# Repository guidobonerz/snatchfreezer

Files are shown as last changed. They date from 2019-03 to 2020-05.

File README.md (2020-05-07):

# SnatchFreezer (Beta)
SnatchFreezer is a project for Highspeed photography

Runs on Windows, Mac and Linux

This project also contains all required software and PCB layouts including:
- JavaFX - Controller Frontend
- Arduino Sketch
- Eagle PCB

Current Features:
- Connect up to six 12V driven valves or similar devices directly with 5 timing entries each.
- Connect up to two camera and/or flashes.

- Load and Save your settings
- Test all channels separately or altogether for 100ms.
- Toggle flushing all or single siphons from UI.
- Set amount of cycle loops
- Set delay time after each cycle loop.
- Describe each channel and/or the whole project
- Presets for TaT and Crown
- View log protocol
- Minimum valve delay/release time combination: 0,015 s -> 15 ms -> 15000 us / 0,004 s -> 4 ms -> 4000 us

Known Bugs:
- Data transfer sometimes hangs

Future plans:
- WLAN and/or Bluetooth Module
- Rest Api
- Android Client

# Build Java Application
mvn jfx:jar

# Download latest Frontend
[Snathfreezer Frontend](https://github.com/guidobonerz/snatchfreezer/blob/develop/download/snatchfreezer.zip)

## Shot 1
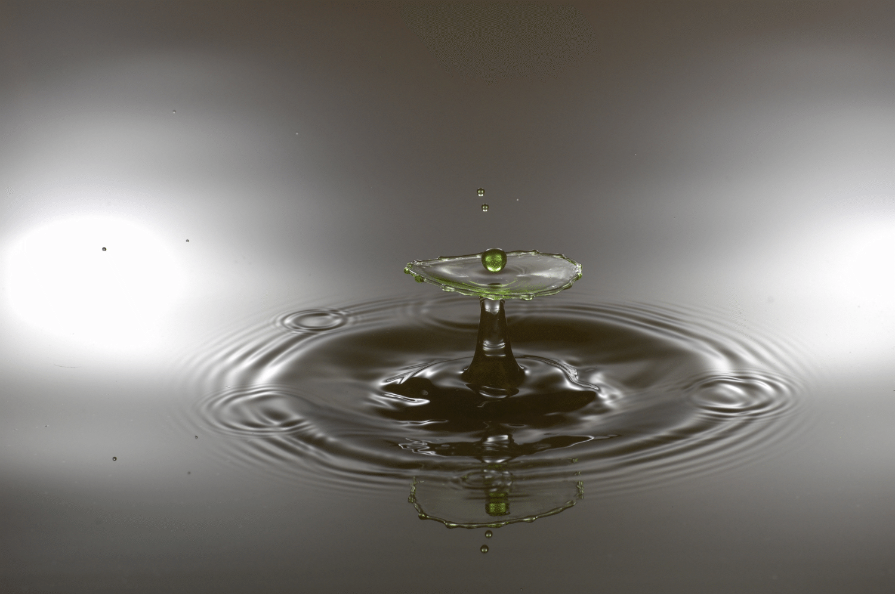
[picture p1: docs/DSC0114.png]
shot1

## Shot 2
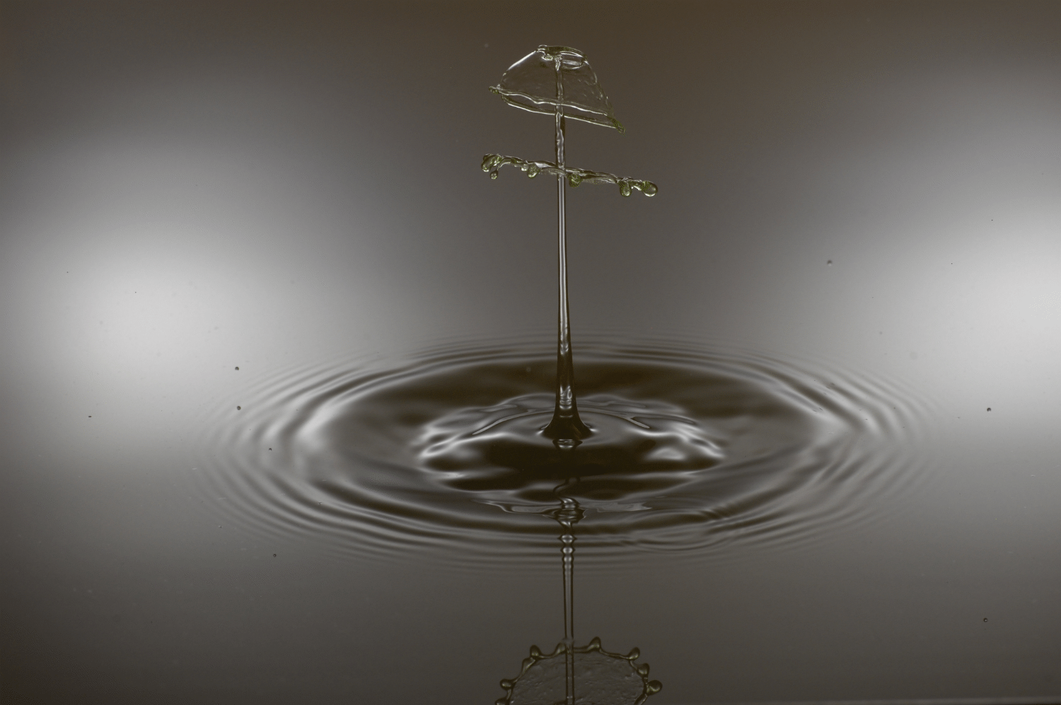
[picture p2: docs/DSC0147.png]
shot2


## Controller View
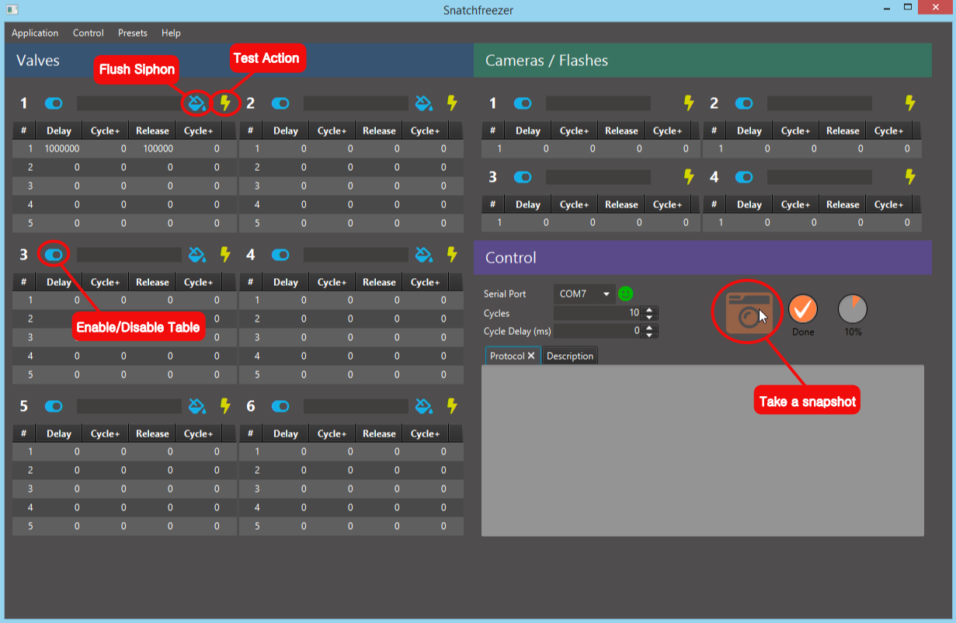
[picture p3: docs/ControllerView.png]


## PCB
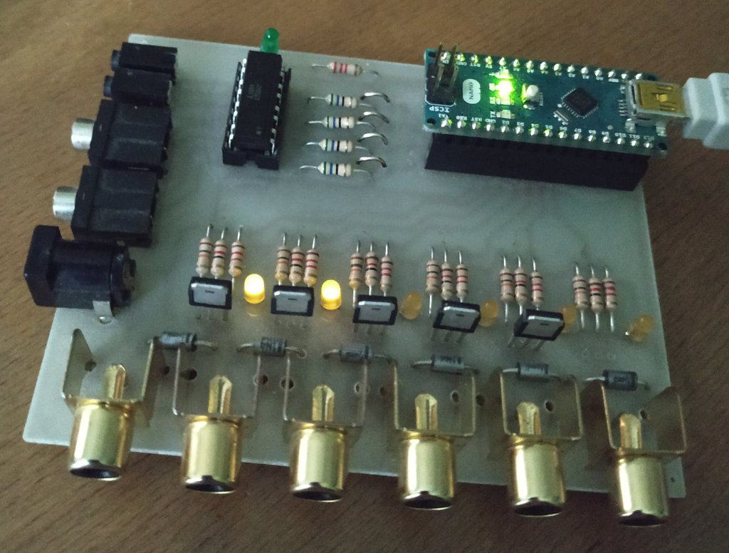
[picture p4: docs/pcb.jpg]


## Frame
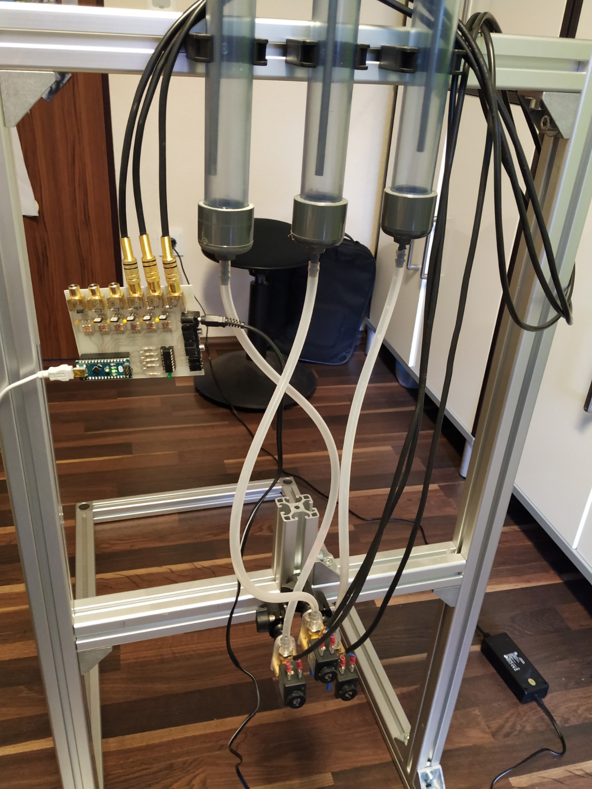
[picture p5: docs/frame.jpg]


## Siphons
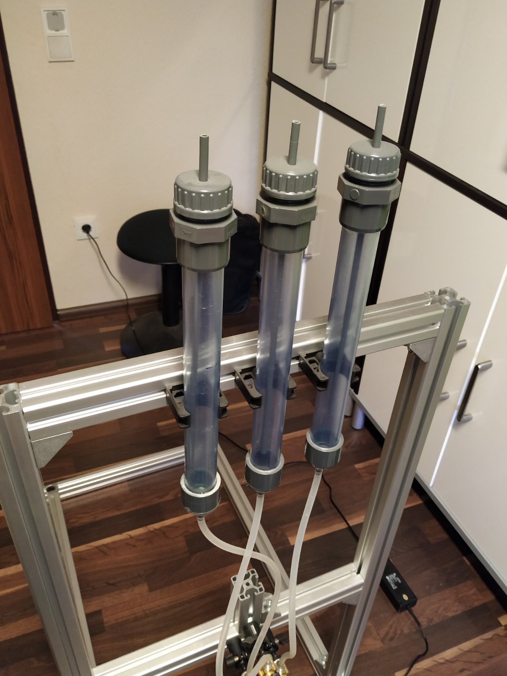
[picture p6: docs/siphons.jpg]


## Valves
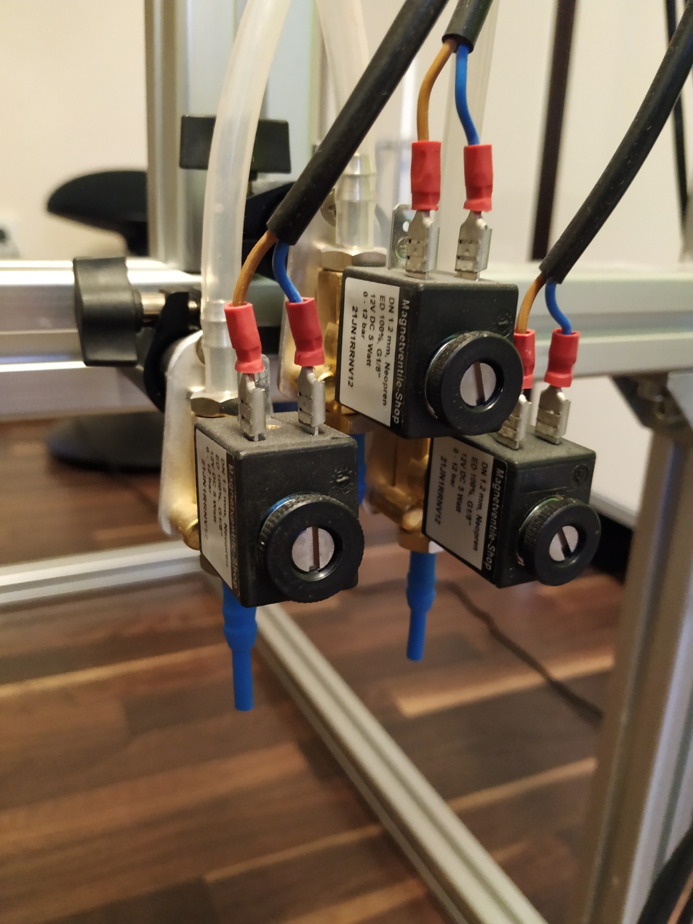
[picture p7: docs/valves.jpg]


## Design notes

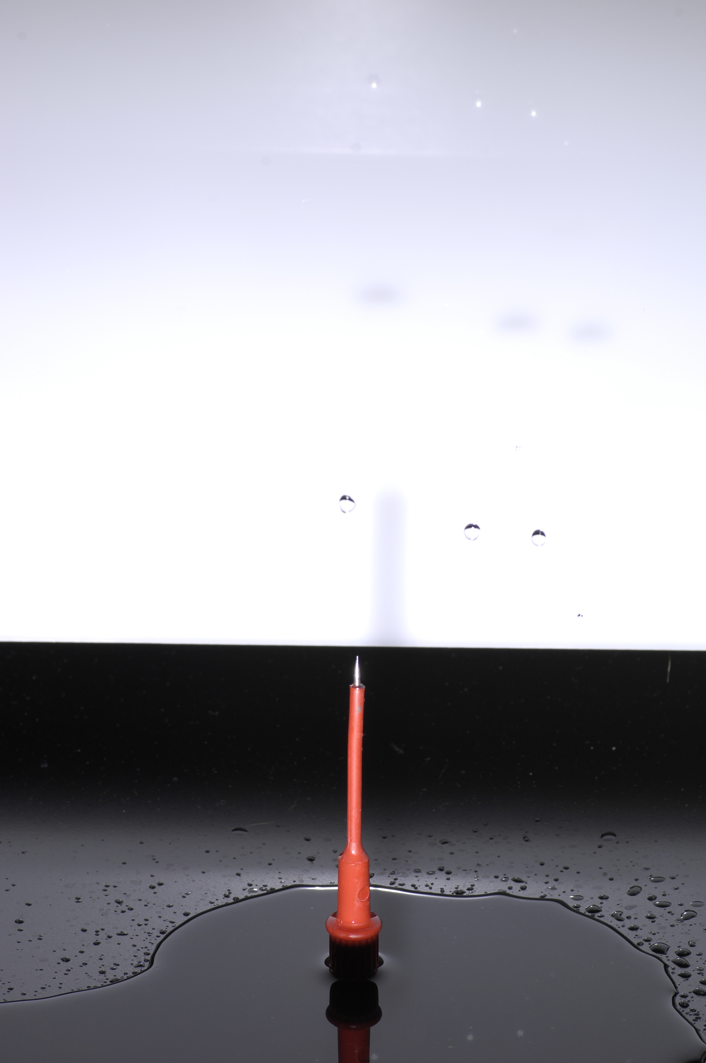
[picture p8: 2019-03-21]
docs/_DSC0161.JPG

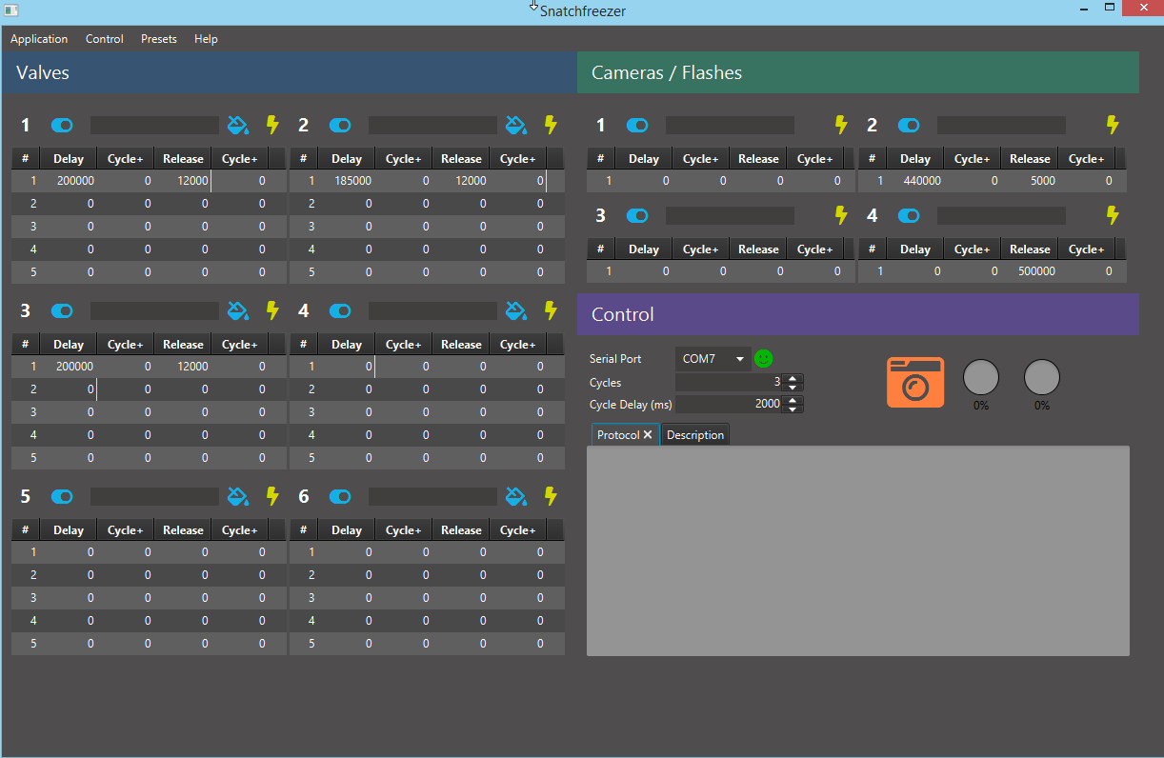
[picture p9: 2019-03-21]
docs/default3.png

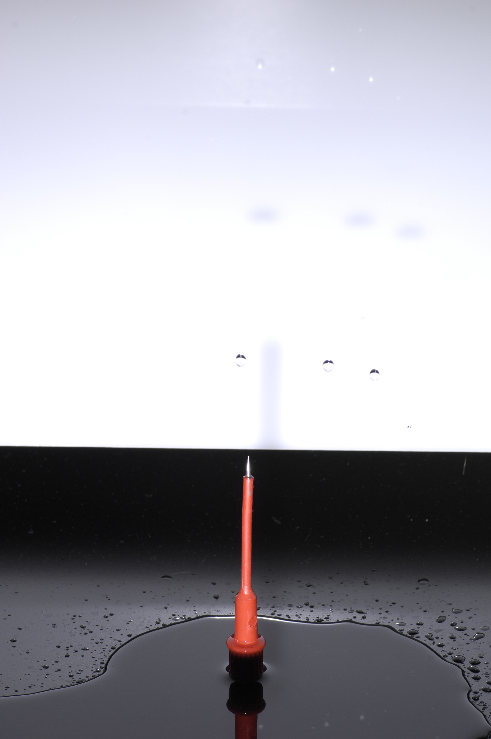
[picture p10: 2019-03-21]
docs/_DSC0163.JPG

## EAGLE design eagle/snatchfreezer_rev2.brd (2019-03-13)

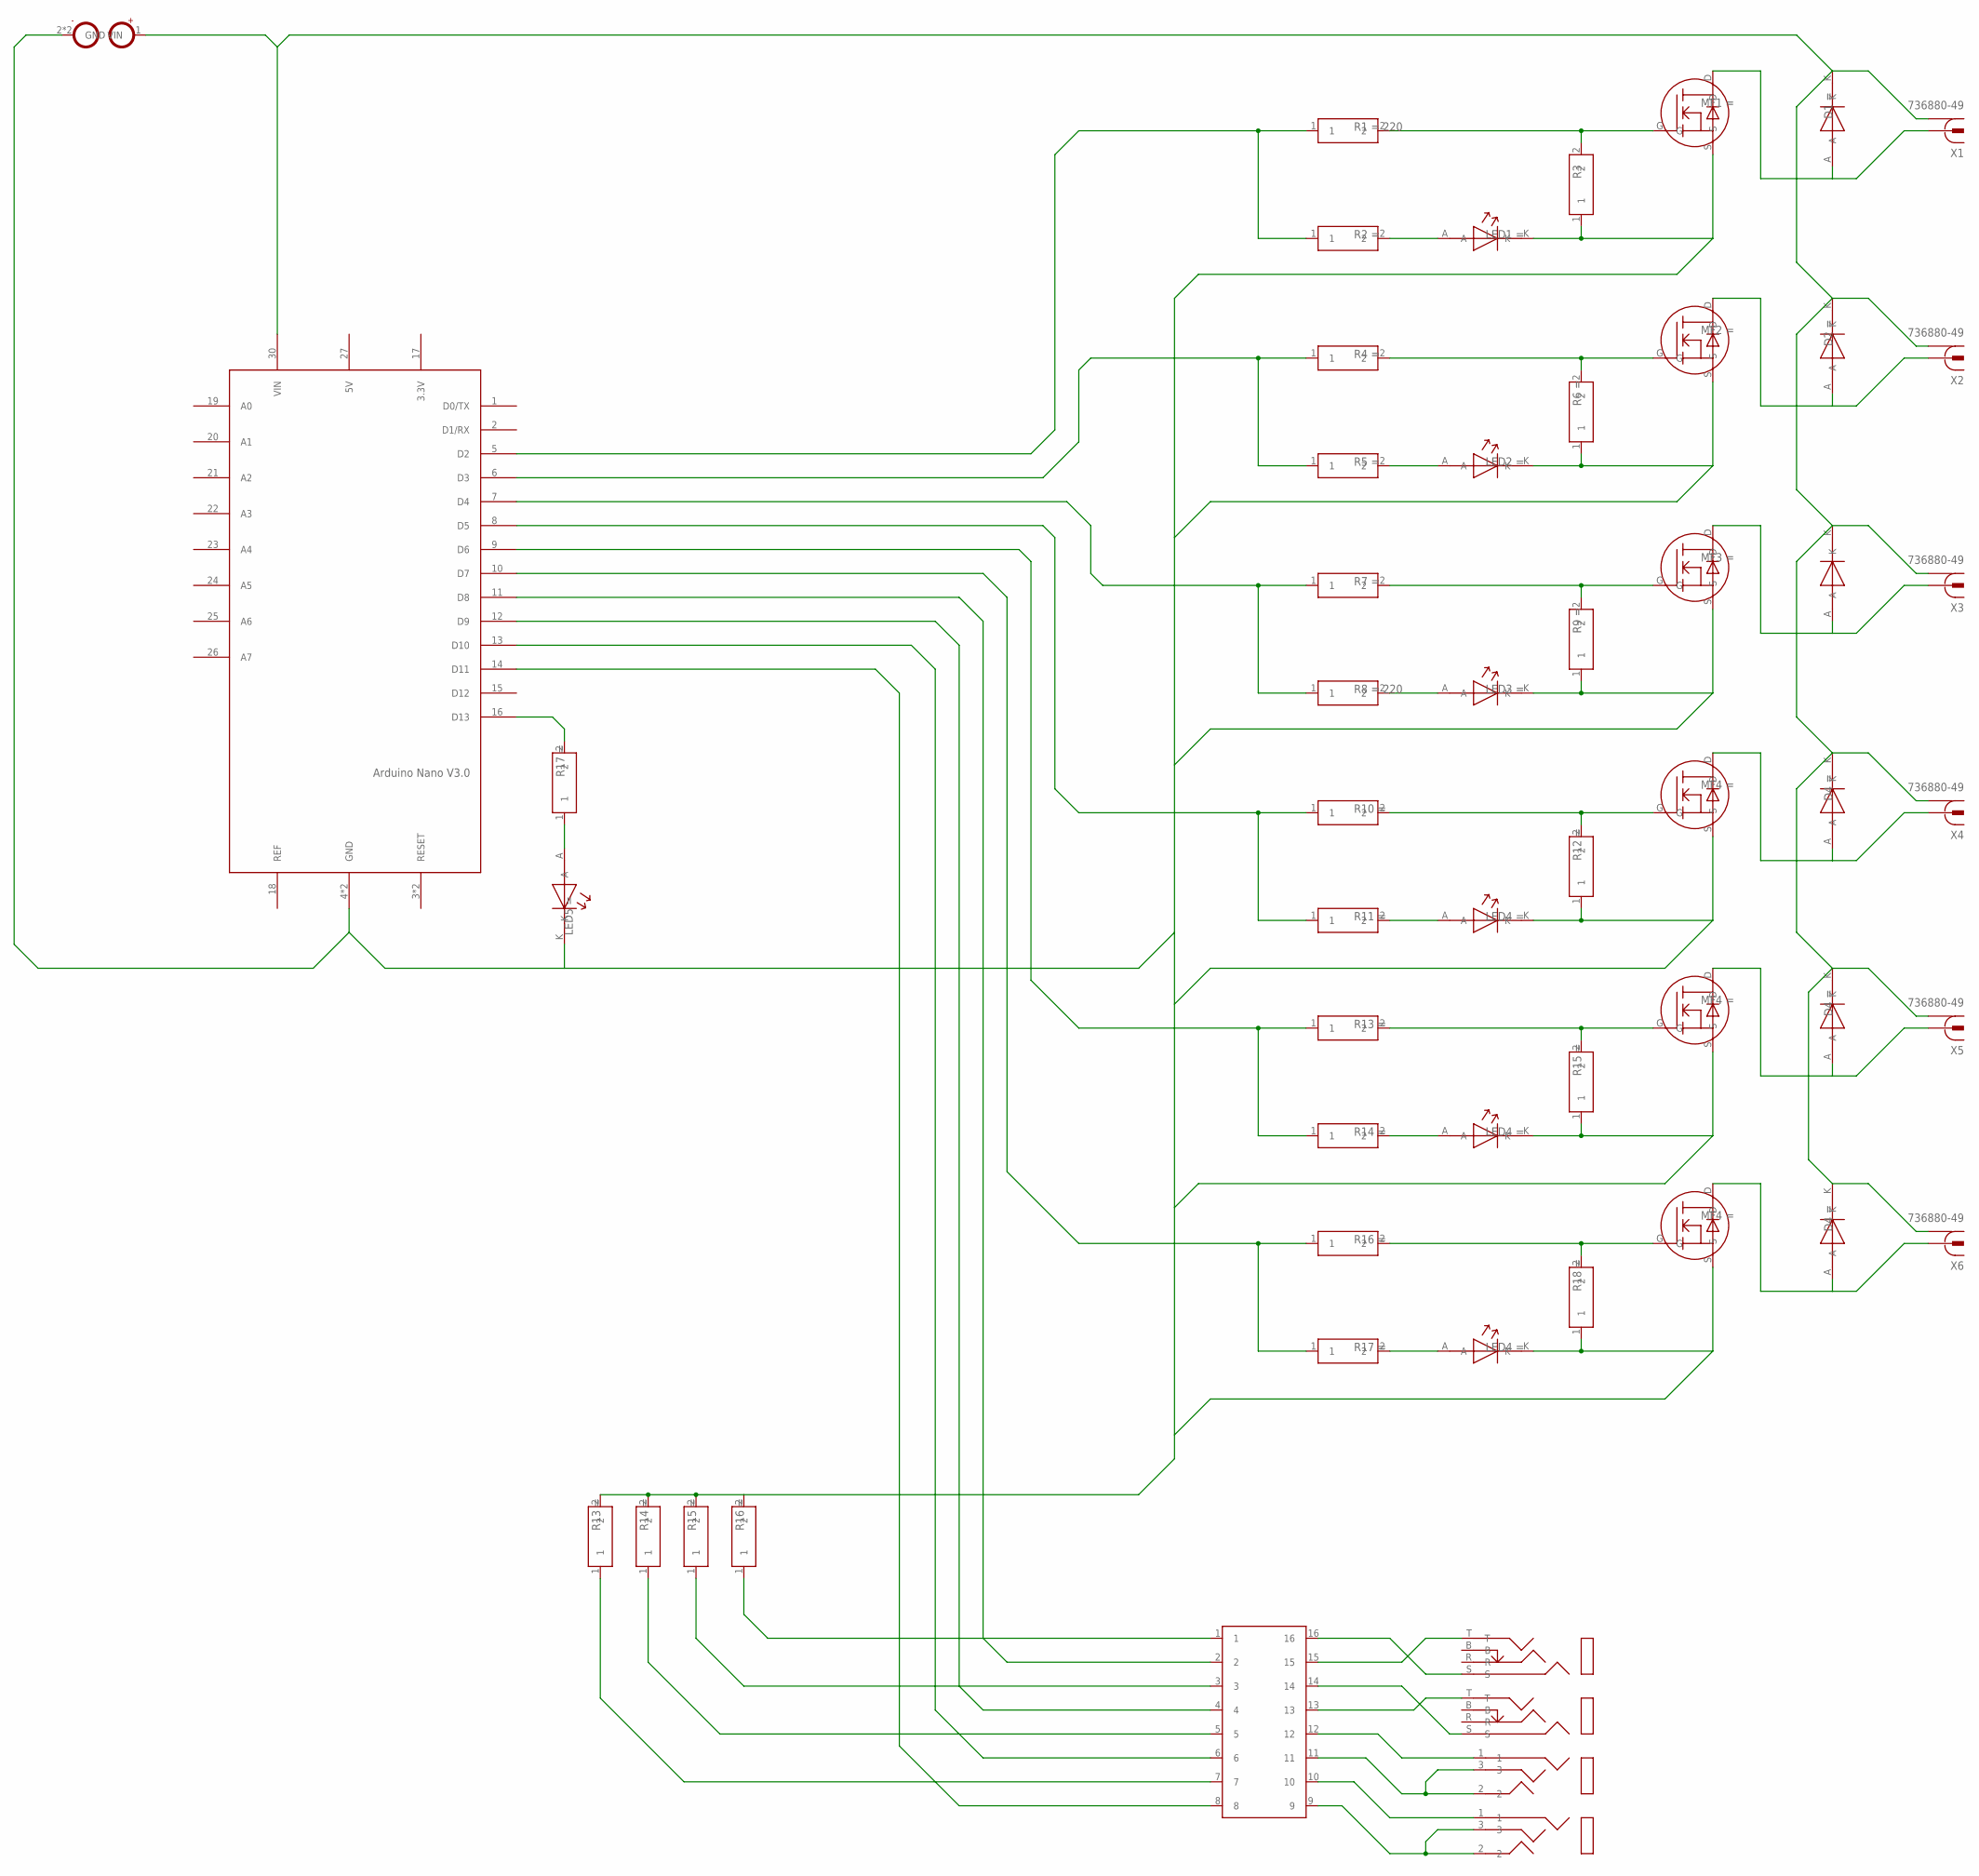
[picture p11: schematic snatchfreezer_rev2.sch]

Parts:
R1, R2, R3, R4, R5, R6, R7, R8, R9, R10, R11, R12, R13, R14, R15, R16, R17, R18: RESISTOR
U$1: ARDUINO_NANO30
U$2, U$3, U$4, U$16, U$20, U$28: IRLR8721
U$5, U$10, U$11, U$17, U$22, U$23, U$31: LED3MM
U$6, U$7: PHONEJACK_35
U$8: IC-16
U$9, U$30, U$37, U$38, U$39: RESISTOR
U$12, U$13, U$14, U$21, U$24, U$32: DIODE
U$36: POWER_CONNECT
U$40, U$41: PHONEJACK_25
X1, X2, X3, X4, X5, X6: 736880-49

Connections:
12V2: U$1.30 (VIN), U$12.K, U$13.K, U$14.K, U$21.K, U$24.K, U$32.K, U$36.1 (VIN), X1.GND (1), X2.GND (1), X3.GND (1), X4.GND (1), X5.GND (1), X6.GND (1)
GND2: R3.1, R6.1, R9.1, R12.1, R15.1, R18.1, U$1.4 (GND), U$1.29 (GND), U$2.S, U$3.S, U$4.S, U$5.K, U$10.K, U$11.K, U$16.S, U$17.K, U$20.S, U$22.K, U$23.K, U$28.S, U$30.2, U$31.K, U$36.2 (GND), U$36.3 (GND), U$37.2, U$38.2, U$39.2
unnamed: R1.2, R3.2, U$2.G
unnamed: U$2.D, U$12.A, X1.SIGNAL (2)
unnamed: R2.2, U$11.A
unnamed: U$7.S, U$8.16
unnamed: U$8.1, U$30.1
unnamed: R1.1, R2.1, U$1.5 (D2)
unnamed: U$3.D, U$13.A, X2.SIGNAL (2)
unnamed: U$8.3, U$37.1
unnamed: U$7.T, U$8.15
unnamed: R5.2, U$10.A
unnamed: R4.2, R6.2, U$3.G
unnamed: R4.1, R5.1, U$1.6 (D3)
unnamed: U$20.D, U$24.A, X3.SIGNAL (2)
unnamed: U$8.5, U$38.1
unnamed: U$8.7, U$39.1
unnamed: R8.2, U$23.A
unnamed: R7.2, R9.2, U$20.G
unnamed: R7.1, R8.1, U$1.7 (D4)
unnamed: U$28.D, U$32.A, X4.SIGNAL (2)
unnamed: U$1.11 (D8), U$8.2
unnamed: U$1.12 (D9), U$8.4
unnamed: R11.2, U$31.A
unnamed: R10.2, R12.2, U$28.G
unnamed: R10.1, R11.1, U$1.8 (D5)
unnamed: U$1.13 (D10), U$8.6
unnamed: U$1.14 (D11), U$8.8
unnamed: U$6.T, U$8.13
unnamed: U$6.S, U$8.14
unnamed: U$4.D, U$14.A, X5.SIGNAL (2)
unnamed: R14.2, U$5.A
unnamed: U$8.12, U$40.1
unnamed: U$8.11, U$40.2, U$40.3
unnamed: U$8.10, U$41.1
unnamed: U$8.9, U$41.2, U$41.3
unnamed: U$1.16 (D13), U$9.2
unnamed: U$9.1, U$22.A
unnamed: R13.2, R15.2, U$4.G
unnamed: R13.1, R14.1, U$1.9 (D6)
unnamed: U$16.D, U$21.A, X6.SIGNAL (2)
unnamed: R17.2, U$17.A
unnamed: R16.2, R18.2, U$16.G
unnamed: R16.1, R17.1, U$1.10 (D7)

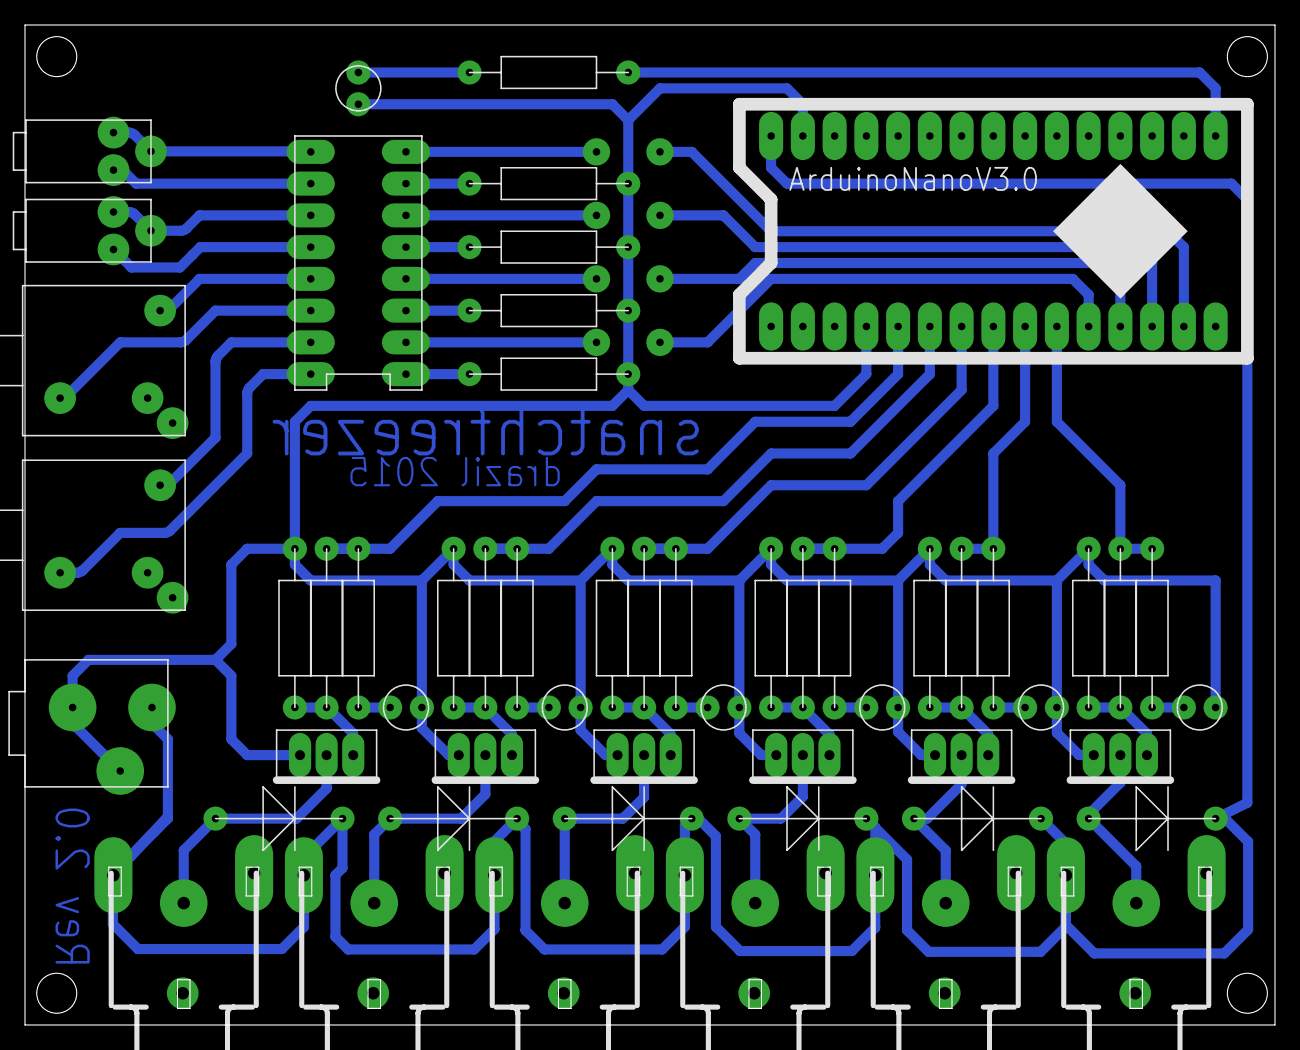
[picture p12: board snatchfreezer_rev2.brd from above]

Board: 2 copper layers, 100.0 x 80.0 mm, 55 parts (0 on the bottom side), 44 nets.

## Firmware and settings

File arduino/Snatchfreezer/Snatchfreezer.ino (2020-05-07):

#include "Constants.h"
#include "Log.h"
#include "NumberConverter.h"
#include "Arduino.h"
#include "SerialHelper.h"

#define arraySize(x) (sizeof(x) / sizeof((x)[0]))

struct ActionTimer
{
  bool started = false;
  bool finished = false;
  uint8_t pin = 0;
  uint8_t timerCount = 0;
  uint8_t maxTimerCount = 0;
  uint32_t targetTime = 0;
  uint32_t delayStartTime[5] = {0, 0, 0, 0, 0};
  uint32_t releaseStartTime[5] = {0, 0, 0, 0, 0};
  uint32_t delayCycleIncrement[5] = {0, 0, 0, 0, 0};
  uint32_t releaseCycleIncrement[5] = {0, 0, 0, 0, 0};
} actionTimer[10];

uint8_t readDataBuffer[100];
uint8_t currentSerialCommand = 0;
uint8_t syncCount = 0;
uint8_t maxActionCount = 0;
uint8_t currentActionCount = 0;
uint8_t maxCycleCount = 0;
uint8_t currentCycleCount = 0;
uint8_t calculatedChecksum = 0;
uint8_t retries = 0;
uint8_t currentRow = 0;
uint32_t cycleDelayTime = 0;
uint32_t targetCycleDelayTime = 0;
uint32_t inc = 0;

uint32_t runMode = 0;

int phase;
int serialReadPhase;
int completeCount = 0;
int dataIndex = 0;
int dataLength = 0;

bool runProgram = false;
bool nextCycle = true;
bool canceled = false;
bool pause = false;

void setup()
{
  Serial.begin(19200, SERIAL_8N1);
  pinMode(ACTIVE_PIN, OUTPUT); //ControlLED
  //pinMode(2, OUTPUT);

  serialReadPhase = READ_DATA_PREFIX;
  phase = PHASE_READ_SERIAL;
  //phase = PHASE_HELLO;
  dataIndex = 0;
  dataLength = 0;
  reset();
}

void clearActions()
{
  currentActionCount = 0;
  completeCount = 0;
  for (uint8_t i = 0; i < arraySize(actionTimer); i++)
  {
    actionTimer[i].timerCount = 0;
    actionTimer[i].targetTime = 0;
    actionTimer[i].finished = false;
    actionTimer[i].started = false;
  }
}

void resetStartTime()
{
  uint32_t startMillis = micros();
  for (uint8_t i = 0; i < arraySize(actionTimer); i++)
  {
    actionTimer[i].targetTime = startMillis + actionTimer[i].delayStartTime[0];
  }
}

void clearSerial()
{
  while (Serial.read() != -1)
  {
  };
}

void reset()
{
  clearSerial();
  clearActions();
  maxActionCount = 0;
  currentCycleCount = 0;
  retries = 0;
  pause = false;
  runProgram = false;
  nextCycle = false;
}

void addAction()
{
  currentActionCount++;
  maxActionCount = currentActionCount;
  Log::info(MESSAGE_MAX_ACTION_COUNT);
}

void setActionPin(uint8_t pin)
{
  actionTimer[currentActionCount - 1].pin = pin;
  pinMode(pin, OUTPUT);
}

void addActionTimings()
{
  actionTimer[currentActionCount - 1].timerCount++;
  actionTimer[currentActionCount - 1].maxTimerCount = actionTimer[currentActionCount - 1].timerCount;
}
void setDelayTime(uint32_t delayTime)
{
  actionTimer[currentActionCount - 1].delayStartTime[actionTimer[currentActionCount - 1].timerCount - 1] = delayTime;
}

void setReleaseTime(uint32_t releaseTime)
{
  actionTimer[currentActionCount - 1].releaseStartTime[actionTimer[currentActionCount - 1].timerCount - 1] = releaseTime;
}

void setStartDelayIncrementTime(uint32_t delayCycleIncrement)
{
  actionTimer[currentActionCount - 1].delayCycleIncrement[actionTimer[currentActionCount - 1].timerCount - 1] = delayCycleIncrement;
}

void setReleaseDelayIncrementTime(uint32_t releaseCycleIncrement)
{
  actionTimer[currentActionCount - 1].releaseCycleIncrement[actionTimer[currentActionCount - 1].timerCount - 1] = releaseCycleIncrement;
}
void setCycleCount(uint8_t cycleCount)
{
  maxCycleCount = cycleCount;
}

void setCycleDelay(uint32_t cycleDelay)
{
  cycleDelayTime = cycleDelay;
}

void loop()
{
  switch (phase)
  {
    case PHASE_HELLO:
      {
        if (Serial)
        {
          Log::echo("HELLO_SNATCHFREEZER");
          phase = PHASE_READ_SERIAL;
        }
        break;
      }
    case PHASE_READ_SERIAL:
      {
        if (Serial && Serial.available() != 0)
        {
          delay(1);
          uint8_t b = (uint8_t)Serial.read();
          parse(b);
        }
        break;
      }
    case PHASE_EXECUTE_COMMAND:
      {
        execute();
        break;
      }
    case PHASE_RUN_PROGRAM:
      {
        switch ((runMode & 0xff))
        {
          case SHOT:
            {
              if (millis() >= targetCycleDelayTime)
              {
                if (!nextCycle)
                {
                  SerialHelper::setCycleCount(currentCycleCount + 1);
                  nextCycle = true;
                  currentActionCount = 0;
                  completeCount = 0;
                  clearActions();
                  resetStartTime();
                  digitalWrite(ACTIVE_PIN, HIGH);
                }
                else
                {
                  //-------------------------------------------------------
                  for (int i = 0; i < maxActionCount; i++)
                  {

                    if (!actionTimer[i].finished)
                    {
                      uint32_t ns = micros();
                      uint8_t currentActionTimerCount = actionTimer[i].timerCount;
                      if (!actionTimer[i].started && ns >= actionTimer[i].targetTime)
                      {
                        actionTimer[i].started = true;
                        inc = actionTimer[i].releaseCycleIncrement[currentActionTimerCount] * currentCycleCount;
                        actionTimer[i].targetTime = ns + actionTimer[i].releaseStartTime[currentActionTimerCount] + inc;

                        digitalWrite(actionTimer[i].pin, HIGH);
                      }

                      if (actionTimer[i].started && ns >= actionTimer[i].targetTime)
                      {
                        digitalWrite(actionTimer[i].pin, LOW);
                        actionTimer[i].started = false;
                        inc = actionTimer[i].delayCycleIncrement[currentActionTimerCount] * currentCycleCount;
                        actionTimer[i].targetTime = ns + actionTimer[i].delayStartTime[currentActionTimerCount] + inc;
                        if (currentActionTimerCount < actionTimer[i].maxTimerCount - 1)
                        {
                          actionTimer[i].timerCount++;
                        }
                        else
                        {
                          actionTimer[i].finished = true;
                          completeCount++;
                        }
                      }
                    }
                  }

                  if (completeCount > maxActionCount - 1)
                  {
                    targetCycleDelayTime = millis() + cycleDelayTime;
                    nextCycle = false;
                    completeCount = 0;
                    currentCycleCount++;
                  }
                  //-------------------------------------------------------
                }
              }

              if (currentCycleCount >= maxCycleCount)
              {
                currentCycleCount = 0;
                digitalWrite(ACTIVE_PIN, LOW);
                SerialHelper::finished();
                phase = PHASE_READ_SERIAL;
              }
              break;
            }
          case TEST:
            {
              uint8_t pin = (runMode >> 8) & 0xff;
              pinMode(pin, OUTPUT);
              digitalWrite(pin, HIGH);
              uint32_t testTime = micros() + 50000;
              while (micros() < testTime)
              {
              }
              digitalWrite(pin, LOW);
              phase = PHASE_READ_SERIAL;
              break;
            }
          case FLUSH_ON:
            {
              uint8_t pin = (runMode >> 8) & 0xff;
              pinMode(pin, OUTPUT);
              digitalWrite(pin, HIGH);
              phase = PHASE_READ_SERIAL;
              break;
            }
          case FLUSH_OFF:
            {
              uint8_t pin = (runMode >> 8) & 0xff;
              pinMode(pin, OUTPUT);
              digitalWrite(pin, LOW);
              phase = PHASE_READ_SERIAL;
              break;
            }
          case HELO:
            {
              Log::echo("HELLO_SNATCHFREEZER");
              phase = PHASE_READ_SERIAL;
              break;
            }
        }
      }
  }
}

void execute()
{
  String s = String("");
  uint32_t value = 0;
  if ((currentSerialCommand & PARAMETER_NUMBER) == PARAMETER_NUMBER)
  {
    Log::debug(MESSAGE_NUMBER_PARAMETER);
    switch (dataLength)
    {
      case BYTE:
        {
          value = NumberConverter::getUInt8(readDataBuffer, 0);
          Log::debug(MESSAGE_BYTE);
          break;
        }
      case WORD:
        {
          value = NumberConverter::getUInt16(readDataBuffer, 0);
          Log::debug(MESSAGE_WORD);
          break;
        }
      case DWORD:
        {
          value = NumberConverter::getUInt32(readDataBuffer, 0);
          Log::debug(MESSAGE_DWORD);
          break;
        }
    }
  }
  else if ((currentSerialCommand & PARAMETER_STRING) == PARAMETER_STRING)
  {
    for (int i = 0; i < dataLength; i++)
    {
      s += (char)readDataBuffer[i];
    }
    Log::debug(MESSAGE_STRING_PARAMETER);
  }
  else if ((currentSerialCommand & PARAMETER_NO) == PARAMETER_NO)
  {
    Log::debug(MESSAGE_NO_PARAMETER);
  }

  switch (currentSerialCommand)
  {

    case COMMAND_RUN:
      {
        Log::info(MESSAGE_RUN);
        runProgram = true;
        runMode = value;
        break;
      }
    case COMMAND_RESET:
      {
        Log::info(MESSAGE_RESET);
        reset();
        break;
      }
    case COMMAND_CANCEL:
      {
        Log::info(MESSAGE_CANCEL);
        canceled = true;
        break;
      }
    case COMMAND_ECHO:
      {
        Log::info(MESSAGE_ECHO);
        Log::echo(s);
        break;
      }
    case COMMAND_SET_LOG_LEVEL:
      {
        Log::info(MESSAGE_SET_LOG_LEVEL);
        Log::setLogLevel(value);
        break;
      }
    case COMMAND_ADD_ACTION:
      {
        Log::info(MESSAGE_ADD_ACTION);
        addAction();
        break;
      }
    case COMMAND_SET_ACTION_PIN:
      {
        Log::info(MESSAGE_SET_ACTION_PIN);
        setActionPin(value);
        break;
      }
    case COMMAND_ADD_ACTION_TIMINGS:
      {
        Log::info(MESSAGE_ADD_ACTION_TIMIMGS);
        addActionTimings();
        break;
      }
    case COMMAND_SET_ACTION_DELAY_TIME:
      {
        Log::info(MESSAGE_SET_ACTION_DELAY);
        setDelayTime(value);
        break;
      }
    case COMMAND_SET_ACTION_DELAY_INCREMENT_TIME:
      {
        Log::info(MESSAGE_SET_ACTION_DELAY_INCREMENT);
        setStartDelayIncrementTime(value);
        break;
      }
    case COMMAND_SET_ACTION_RELEASE_TIME:
      {
        Log::info(MESSAGE_SET_ACTION_RELEASE);
        setReleaseTime(value);
        break;
      }
    case COMMAND_SET_ACTION_RELEASE_INCREMENT_TIME:
      {
        Log::info(MESSAGE_SET_ACTION_RELEASE_INCREMENT);
        setReleaseDelayIncrementTime(value);
        break;
      }
    case COMMAND_SET_CYCLE_COUNT:
      {
        Log::info(MESSAGE_SET_CYCLE_COUNT);
        setCycleCount(value);
        break;
      }
    case COMMAND_SET_CYCLE_DELAY:
      {
        Log::info(MESSAGE_SET_CYCLE_DELAY);
        setCycleDelay(value);
        break;
      }
  }

  SerialHelper::sendNextCommand();
  serialReadPhase = READ_DATA_PREFIX;
  if (runProgram)
  {
    phase = PHASE_RUN_PROGRAM;
    runProgram = false;
    clearActions();
    resetStartTime();
  }
  else
  {
    phase = PHASE_READ_SERIAL;
  }
}

void parse(uint8_t data)
{
  switch (serialReadPhase)
  {
    case READ_DATA_PREFIX:
      {
        uint8_t b = data;
        calculatedChecksum ^= b;

        switch (b)
        {
          case SYNCBYTE1:
            {
              serialReadPhase = READ_DATA_PREFIX;
              Log::debug(MESSAGE_SYNC1);
              ++syncCount;
              break;
            }
          case SYNCBYTE2:
            {
              Log::debug(MESSAGE_SYNC2);
              ++syncCount;
              if (syncCount == 2)
              {
                serialReadPhase = READ_COMMAND;
                syncCount = 0;
              }
              break;
            }
        }
        break;
      }

    case READ_COMMAND:
      {
        Log::debug(MESSAGE_READ_COMMAND);
        currentSerialCommand = data;
        calculatedChecksum ^= (uint8_t)currentSerialCommand;
        dataLength = 0;
        dataIndex = 0;
        serialReadPhase = READ_LENGTH;
        switch (currentSerialCommand)
        {
          case COMMAND_ADD_ACTION:
          case COMMAND_ADD_ACTION_TIMINGS:
          // case COMMAND_RUN:
          case COMMAND_RESET:
          case COMMAND_CANCEL:
          case COMMAND_FINISHED:
          case COMMAND_NEXT:
          case COMMAND_REPEAT:
            {
              serialReadPhase = READ_DATA;
              break;
            }
        }
        break;
      }
    case READ_LENGTH:
      {
        Log::debug(MESSAGE_READ_LENGTH);
        dataLength = data;
        dataIndex = 0;
        calculatedChecksum ^= (uint8_t)dataLength;
        serialReadPhase = READ_DATA;
        break;
      }
    case READ_DATA:
      {
        serialReadPhase = READ_DATA;
        if (dataIndex < dataLength)
        {
          Log::debug(MESSAGE_READ_DATA);
          uint8_t b = data;
          calculatedChecksum ^= b;
          readDataBuffer[dataIndex++] = b;
        }
        else
        {
          if (retries < 3)
          {
            Log::debug(MESSAGE_READ_CHECKSUM);

            if (data != calculatedChecksum)
            {
              Log::error(MESSAGE_CHECKSUM_ERROR);
              retries++;
              SerialHelper::repeatCommand();
            }
            else
            {
              Log::debug(MESSAGE_CHECKSUM_OK);
              retries = 0;
              calculatedChecksum = 0;
              phase = PHASE_EXECUTE_COMMAND;
            }
          }
          else
          {
            SerialHelper::cancel();
          }
        }
        break;
      }
  }
}

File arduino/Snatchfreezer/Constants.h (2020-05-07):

#pragma once
#include "Arduino.h"
const int PARAMETER_NO = B00000000;
const int PARAMETER_STRING = B10000000;
const int PARAMETER_NUMBER = B11000000;
const int SYNCBYTE1 = 0xaa;
const int SYNCBYTE2 = 0x55;
const int COMMAND_SET_ACTION_PIN = B11000001;
const int COMMAND_SET_ACTION_DELAY_TIME = B11000010;
const int COMMAND_SET_ACTION_RELEASE_TIME = B11000011;
const int COMMAND_SET_ACTION_DELAY_INCREMENT_TIME = B11000100;
const int COMMAND_SET_ACTION_RELEASE_INCREMENT_TIME = B11000101;
const int COMMAND_SET_CYCLE_COUNT = B11000110;
const int COMMAND_SET_CYCLE_DELAY = B11000111;
const int COMMAND_RUN = B11001001;
const int COMMAND_SEND_RESPONSE = B11001011;
const int COMMAND_ADD_ACTION = B00000001;
const int COMMAND_ADD_ACTION_TIMINGS = B00000010;
const int COMMAND_NEXT = B00000011;
const int COMMAND_REPEAT = B00000100;
const int COMMAND_SET_LOG_LEVEL = B11001011;
const int COMMAND_CANCEL = B00000111;
const int COMMAND_RESET = B00001000;
const int COMMAND_FINISHED = B00001001;
const int COMMAND_DUMMY = B00111111;
const int COMMAND_ECHO = B10001001;
const int COMMAND_LOG_INFO = B11001010;
const int COMMAND_LOG_DEBUG = B11001011;
const int COMMAND_LOG_ERROR = B11001100;
const int COMMAND_LOG_OFF = B10001110;

const int SHOT = 0;
const int FLUSH_ON = 1;
const int FLUSH_OFF = 2;
const int TEST = 3;
const int HELO = 4;

const int MESSAGE_BYTE = 1;
const int MESSAGE_WORD = 2;
const int MESSAGE_DWORD = 3;
const int MESSAGE_STRING_PARAMETER = 4;
const int MESSAGE_NUMBER_PARAMETER = 5;
const int MESSAGE_NO_PARAMETER = 6;
const int MESSAGE_RUN = 7;
const int MESSAGE_RESET = 8;
const int MESSAGE_CANCEL = 9;
const int MESSAGE_ECHO = 10;
const int MESSAGE_SET_LOG_LEVEL = 11;
const int MESSAGE_ADD_ACTION = 12;
const int MESSAGE_SET_ACTION_PIN = 13;
const int MESSAGE_ADD_ACTION_TIMIMGS = 14;
const int MESSAGE_SET_ACTION_DELAY = 15;
const int MESSAGE_SET_ACTION_DELAY_INCREMENT = 16;
const int MESSAGE_SET_ACTION_RELEASE = 17;
const int MESSAGE_SET_ACTION_RELEASE_INCREMENT = 18;
const int MESSAGE_SET_CYCLE_COUNT = 19;
const int MESSAGE_SET_CYCLE_DELAY = 20;
const int MESSAGE_SYNC1 = 21;
const int MESSAGE_SYNC2 = 22;
const int MESSAGE_READ_COMMAND = 23;
const int MESSAGE_READ_LENGTH = 24;
const int MESSAGE_READ_DATA = 25;
const int MESSAGE_READ_CHECKSUM = 26;
const int MESSAGE_CHECKSUM_ERROR = 27;
const int MESSAGE_CHECKSUM_OK = 28;
const int MESSAGE_MAX_ACTION_COUNT = 29;
const int MESSAGE_DUMMY = 99;

//const int COMMAND_RUN = 10;

const int READ_DATA_PREFIX = 10;
const int READ_COMMAND = 20;
const int READ_LENGTH = 30;
const int READ_DATA = 40;
const int READ_CHECKSUM = 50;
const int EXECUTE_COMMAND = 60;

const int CAMERA1_PIN = 10;
const int CAMERA2_PIN = 11;
const int FLASH1_PIN = 8;
const int FLASH2_PIN = 9;
const int VALVE1_PIN = 2;
const int VALVE2_PIN = 3;
const int VALVE3_PIN = 4;
const int VALVE4_PIN = 5;
const int VALVE5_PIN = 6;
const int VALVE6_PIN = 7;
//const int BUTTON_PIN = 1;// unset
const int ACTIVE_PIN = 13;
const int INACTIVE = 100;

const int PHASE_HELLO = 0;
const int PHASE_READ_SERIAL = 10;
const int PHASE_EXECUTE_COMMAND = 20;
const int PHASE_RUN_PROGRAM = 30;

const uint8_t COMMAND_WAIT_FOR_SERIAL_DATA = 0;
const uint8_t COMMAND_PARSE_BUFFER = 1;

const uint8_t BYTE = 1;
const uint8_t WORD = 2;
const uint8_t DWORD = 4;

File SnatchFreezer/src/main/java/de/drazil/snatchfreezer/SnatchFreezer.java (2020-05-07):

package de.drazil.snatchfreezer;

import static de.drazil.util.Constants.COMMAND_CANCEL;
import static de.drazil.util.Constants.COMMAND_DUMMY;
import static de.drazil.util.Constants.COMMAND_ECHO;
import static de.drazil.util.Constants.COMMAND_FINISHED;
import static de.drazil.util.Constants.COMMAND_LOG_DEBUG;
import static de.drazil.util.Constants.COMMAND_LOG_ERROR;
import static de.drazil.util.Constants.COMMAND_LOG_INFO;
import static de.drazil.util.Constants.COMMAND_LOG_OFF;
import static de.drazil.util.Constants.COMMAND_NEXT;
import static de.drazil.util.Constants.COMMAND_REPEAT;
import static de.drazil.util.Constants.COMMAND_RESET;
import static de.drazil.util.Constants.COMMAND_RUN;
import static de.drazil.util.Constants.COMMAND_SET_CYCLE_COUNT;
import static de.drazil.util.Constants.EXECUTE_COMMAND;
import static de.drazil.util.Constants.FLUSH_OFF;
import static de.drazil.util.Constants.FLUSH_ON;
import static de.drazil.util.Constants.HELO;
import static de.drazil.util.Constants.MESSAGE_ADD_ACTION;
import static de.drazil.util.Constants.MESSAGE_ADD_ACTION_TIMIMGS;
import static de.drazil.util.Constants.MESSAGE_BYTE;
import static de.drazil.util.Constants.MESSAGE_CANCEL;
import static de.drazil.util.Constants.MESSAGE_CHECKSUM_ERROR;
import static de.drazil.util.Constants.MESSAGE_CHECKSUM_OK;
import static de.drazil.util.Constants.MESSAGE_DWORD;
import static de.drazil.util.Constants.MESSAGE_ECHO;
import static de.drazil.util.Constants.MESSAGE_MAX_ACTION_COUNT;
import static de.drazil.util.Constants.MESSAGE_NO_PARAMETER;
import static de.drazil.util.Constants.MESSAGE_NUMBER_PARAMETER;
import static de.drazil.util.Constants.MESSAGE_READ_CHECKSUM;
import static de.drazil.util.Constants.MESSAGE_READ_COMMAND;
import static de.drazil.util.Constants.MESSAGE_READ_DATA;
import static de.drazil.util.Constants.MESSAGE_READ_LENGTH;
import static de.drazil.util.Constants.MESSAGE_RESET;
import static de.drazil.util.Constants.MESSAGE_RUN;
import static de.drazil.util.Constants.MESSAGE_SET_ACTION_DELAY;
import static de.drazil.util.Constants.MESSAGE_SET_ACTION_DELAY_INCREMENT;
import static de.drazil.util.Constants.MESSAGE_SET_ACTION_PIN;
import static de.drazil.util.Constants.MESSAGE_SET_ACTION_RELEASE;
import static de.drazil.util.Constants.MESSAGE_SET_ACTION_RELEASE_INCREMENT;
import static de.drazil.util.Constants.MESSAGE_SET_CYCLE_COUNT;
import static de.drazil.util.Constants.MESSAGE_SET_CYCLE_DELAY;
import static de.drazil.util.Constants.MESSAGE_SET_LOG_LEVEL;
import static de.drazil.util.Constants.MESSAGE_STRING_PARAMETER;
import static de.drazil.util.Constants.MESSAGE_SYNC1;
import static de.drazil.util.Constants.MESSAGE_SYNC2;
import static de.drazil.util.Constants.MESSAGE_WORD;
import static de.drazil.util.Constants.OFF;
import static de.drazil.util.Constants.PARAMETER_NUMBER;
import static de.drazil.util.Constants.PARAMETER_STRING;
import static de.drazil.util.Constants.READ_COMMAND;
import static de.drazil.util.Constants.READ_DATA;
import static de.drazil.util.Constants.READ_DATA_PREFIX;
import static de.drazil.util.Constants.READ_LENGTH;
import static de.drazil.util.Constants.SHOT;
import static de.drazil.util.Constants.SYNCBYTE1;
import static de.drazil.util.Constants.SYNCBYTE2;
import static de.drazil.util.Constants.TEST;

import java.io.File;
import java.util.ArrayList;
import java.util.Iterator;
import java.util.List;
import java.util.Locale;
import java.util.ResourceBundle;
import java.util.concurrent.Executors;
import java.util.concurrent.ScheduledExecutorService;
import java.util.concurrent.TimeUnit;

import com.fasterxml.jackson.databind.ObjectMapper;
import com.fasterxml.jackson.databind.SerializationFeature;
import com.fazecast.jSerialComm.SerialPort;
import com.fazecast.jSerialComm.SerialPortDataListener;
import com.fazecast.jSerialComm.SerialPortEvent;

import de.drazil.snatchfreezer.model.ActionBean;
import de.drazil.snatchfreezer.model.ActionItemBean;
import de.drazil.snatchfreezer.model.ActionItemPropertyBean;
import de.drazil.snatchfreezer.model.Settings;
import de.drazil.util.ArrayUtil;
import de.drazil.util.ConfigurationBuilder;
import de.drazil.util.EditCell;
import de.drazil.util.Long2StringConverter;
import de.drazil.util.NumericConverter;
import javafx.application.Application;
import javafx.application.Platform;
import javafx.beans.property.Property;
import javafx.collections.FXCollections;
import javafx.collections.ObservableList;
import javafx.event.EventHandler;
import javafx.geometry.Insets;
import javafx.scene.Node;
import javafx.scene.Scene;
import javafx.scene.control.Alert;
import javafx.scene.control.Alert.AlertType;
import javafx.scene.control.Button;
import javafx.scene.control.CheckMenuItem;
import javafx.scene.control.ComboBox;
import javafx.scene.control.Label;
import javafx.scene.control.Menu;
import javafx.scene.control.MenuBar;
import javafx.scene.control.MenuItem;
import javafx.scene.control.ProgressIndicator;
import javafx.scene.control.ScrollPane;
import javafx.scene.control.SeparatorMenuItem;
import javafx.scene.control.Spinner;
import javafx.scene.control.Tab;
import javafx.scene.control.TabPane;
import javafx.scene.control.TableColumn;
import javafx.scene.control.TablePosition;
import javafx.scene.control.TableView;
import javafx.scene.control.TextArea;
import javafx.scene.control.TextField;
import javafx.scene.control.TitledPane;
import javafx.scene.control.ToggleButton;
import javafx.scene.control.ToolBar;
import javafx.scene.control.cell.PropertyValueFactory;
import javafx.scene.input.KeyCode;
import javafx.scene.layout.GridPane;
import javafx.scene.layout.HBox;
import javafx.scene.layout.Priority;
import javafx.scene.layout.Region;
import javafx.scene.layout.VBox;
import javafx.scene.text.Font;
import javafx.stage.FileChooser;
import javafx.stage.FileChooser.ExtensionFilter;
import javafx.stage.Stage;
import javafx.stage.WindowEvent;
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
